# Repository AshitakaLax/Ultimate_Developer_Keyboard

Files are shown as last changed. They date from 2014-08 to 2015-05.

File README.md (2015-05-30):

Ultimate_Developer_Keyboard
===========================

Ultimate left single hand keyboard for Developing, Macros, and gaming. Code for MCU, Code for Windows service program, keyboard Hardware schematics, Keyboard Plastic templates.

### GOALS

While there are many great keyboards out there, I'm not aware of any that can support all of these.

1. Lower Cost (Many commercial keyboards have a low price)
2. Modularity (Nearly No keyboard is modular, but there are many nice features with modularity)
3. Open Source (Parallelized work is always faster, This is a hobby for me)
4. Flexible (If I want to have 64 keys I can, If I want 105 keys, I can, If I want 1000 keys I can), if I want it to be wireless, it can be,
5. Powerful (I don't want to be limited by the hardware as to what It can support).
6. Energy Flexible ( If I want to attach a fan, and LED lamp, I can. If I want to run off a Coin cell battery I can.)

I naturally can see the conflicting attributes in the list above. But with enough fore site, and structure, It should be possible.

### ROAD MAP

These are the core features with the new version of the keyboard.

1. Layout Modular components(Keys, brains, Communications)
2. Create the Bare bones keyboard(pretty much copy 64keys, and Ergodox, directly to a USB connection)
3. Support direct I/O connection from one board to the other(like 64 keys)
4. Have keyboard Right hand keyboard run off coin cell battery, and be wireless

This Project is broken down into 3 sections

1. Keyboard Software - this is the embedded code on a custom dev board(Atmel Sam4E), with hopes to move to a smaller chip to save cost.
2. Windows Software - this will be the smart portion of the system. It will determine the current IDE, and switch to it's custom keyboard layout.
3. Keyboard Hardware - This is all of the documentation for the hardware of this system, schematics, STL's, etc...

This system will be developed with Industrial quality tools, mainly because I like my time.

Keyboard Software Tools - Atmel Studio 6.2
Windows Software Tools - Visual Studio 2010 Ultimate
Keyboard Hardware Tools - (PCB)Altium Designer ,(Plastics) TBD

Scratch Notes

right side board structure.

SAM L21E(32 pin chip 25 IO) PL0
coin cell battery ~250mAh rechargeable
cpu pwr use 25 uA/Mhz (since speed isn't a factor) 1.2 mA when active
//since we can sleep, with a specific wakeup pin we can use
sleep/standby is 25uAmp.
NRF24L01+
tx is 7 mA
power down mode 4.2uA

standby sum of power
4.2uA
25uA

This right hand design is a asynchronous design to send keys as soon as they are pressed.
 and as soon as they aren't pressed

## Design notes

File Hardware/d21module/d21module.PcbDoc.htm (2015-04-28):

Reporting Options

# File in Previous Format

Date | : | 11/26/2014
Time | : | 1:07:59 PM
Filename | : | C:\Users\MIS\Desktop\workspace\Ultimate_Developer_Keyboard\Hardware\d21module\d21module.PcbDoc

Version | Warning
Release 12 | CAUTION - Air Gap Width previously controlled by Clearance rule is now controlled by Polygon Connect Style rule's newly introduced Air Gap Width (set to default value). Suggest reviewing each Polygon Connect Style rule's Air Gap Width attribute for correctness.
Release 13 | CAUTION - Silkscreen Over Component Pads Rules are converted to Silk To Solder Mask Clearance Rules. Suggest examining rule scopes for accuracy.

This file was generated by an earlier version of the software

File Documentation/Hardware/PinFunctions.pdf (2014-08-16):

P1

| | 3.3V | 1 | 2 | GND
MoistureSensor1 | I/O | PD0 | 3 | 4 | PB13 | I/O | MoistureSensor4
MoistureSensor2 | I/O | PB14 | 5 | 6 | PD1 | I/O | MoistureSensor5
MoistureSensor3 | I/O | PD2 | 7 | 8 | PA29 | I/O | MoistureSensor6

P2

3.3V PB1 | 1 | 2 | GND PB0
TXD0 | | 3 | 4 | RXD0
| A16 | PA20 | 5 | 6 | PA19 | A15
I/O | PA17 | 7 | 8 | PB2 | CTS0/AFE1_AD0 Voltage Sensor
CurrentSensor | AFE1_AD1 | PB3 | 9 | 10 | PA21 | RXD1
| I/O | PD30 | 11 | 12 | PA22 | TXD1
| MOSI | PA13 | 13 | 14 | PA16 | TIOB1 | Thruster
| SCK1/A19 | PA23 | 15 | 16 | PD27 | I/O
Thruster | TIOA1 | PA15 | 17 | 18 | PA14 | SPCK
| I/O | PD25 | 19 | 20 | PD26 | I/O
| I/O | PD24 | 21 | 22 | PA24 | RTS1/A20
Headlight | PWMH3 | PD23 | 23 | 24 | PA25 | CTS1/A23
Headlight | PWMH2 | PD22 | 25 | 26 | PA26 | TIOA2 | Thruster
Thruster | PWMH1 | PD21 | 27 | 28 | PA11 | I/O
Thruster | PWMH0 | PD20 | 29 | 30 | PA10 | UTXD0
| I/O | PD19 | 31 | 32 | PA12 | MISO

P3

| | 3.3V | 1 | 2 | GND
| I/O | PD3 | 3 | 4 | PD4 | I/O
| I/O | PD5 | 5 | 6 | PD6 | I/O
| I/O | PD7 | 7 | 8 | PA31 | I/O
| I/O | PA30 | 9 | 10 | PA6 | UTXD1
| I/O | PD8 | 11 | 12 | PA28 | I/O
| I/O | PD9 | 13 | 14 | PD29 | I/O
| I/O | PD15 | 15 | 16 | PA0 | TIOA0 | Thruster
| I/O | PD10 | 17 | 18 | PA1 | TIOB0 | Thruster
| I/O | PD11 | 19 | 20 | PA2 | I/O
| I/O | PD12 | 21 | 22 | PA3 | TWD0 | Accelerometer
| I/O | PD13 | 23 | 24 | PD14 | I/O
| I/O | PD16 | 25 | 26 | PA4 | TWCK0 | Accelerometer
Sonar1 | URXD0 | PA9 | 27 | 28 | PD17 | I/O
Sonar2 | URXD1 | PA5 | 29 | 30 | PD28 | I/O
Thruster | TIOB2 | PA27 | 31 | 32 | PD18 | I/O

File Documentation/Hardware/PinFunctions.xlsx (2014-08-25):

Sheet: roboSub
 |  |  | P1
 |  | 3.3V | 1 | 2 | GND
MoistureSensor1 | I/O | PD0 | 3 | 4 | PB13 | I/O | MoistureSensor4
MoistureSensor2 | I/O | PB14 | 5 | 6 | PD1 | I/O | MoistureSensor5
MoistureSensor3 | I/O | PD2 | 7 | 8 | PA29 | I/O | MoistureSensor6
 |  |  | P2
 |  | 3.3V | 1 | 2 | GND
 | TXD0 | PB1 | 3 | 4 | PB0 | RXD0
 | A16 | PA20 | 5 | 6 | PA19 | A15
 | I/O | PA17 | 7 | 8 | PB2 | CTS0/AFE1_AD0 | Voltage Sensor
CurrentSensor | AFE1_AD1 | PB3 | 9 | 10 | PA21 | RXD1
 | I/O | PD30 | 11 | 12 | PA22 | TXD1
 | MOSI | PA13 | 13 | 14 | PA16 | TIOB1 | Thruster
 | SCK1/A19 | PA23 | 15 | 16 | PD27 | I/O
Thruster | TIOA1 | PA15 | 17 | 18 | PA14 | SPCK
 | I/O | PD25 | 19 | 20 | PD26 | I/O
 | I/O | PD24 | 21 | 22 | PA24 | RTS1/A20
Headlight | PWMH3 | PD23 | 23 | 24 | PA25 | CTS1/A23
Headlight | PWMH2 | PD22 | 25 | 26 | PA26 | TIOA2 | Thruster
Thruster | PWMH1 | PD21 | 27 | 28 | PA11 | I/O
Thruster | PWMH0 | PD20 | 29 | 30 | PA10 | UTXD0
 | I/O | PD19 | 31 | 32 | PA12 | MISO
 |  |  | P3
 |  | 3.3V | 1 | 2 | GND
 | I/O | PD3 | 3 | 4 | PD4 | I/O
 | I/O | PD5 | 5 | 6 | PD6 | I/O
 | I/O | PD7 | 7 | 8 | PA31 | I/O
 | I/O | PA30 | 9 | 10 | PA6 | UTXD1
 | I/O | PD8 | 11 | 12 | PA28 | I/O
 | I/O | PD9 | 13 | 14 | PD29 | I/O
 | I/O | PD15 | 15 | 16 | PA0 | TIOA0 | Thruster
 | I/O | PD10 | 17 | 18 | PA1 | TIOB0 | Thruster
 | I/O | PD11 | 19 | 20 | PA2 | I/O
 | I/O | PD12 | 21 | 22 | PA3 | TWD0 | Accelerometer
 | I/O | PD13 | 23 | 24 | PD14 | I/O
 | I/O | PD16 | 25 | 26 | PA4 | TWCK0 | Accelerometer
Sonar1 | URXD0 | PA9 | 27 | 28 | PD17 | I/O
Sonar2 | URXD1 | PA5 | 29 | 30 | PD28 | I/O
Thruster | TIOB2 | PA27 | 31 | 32 | PD18 | I/O

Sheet: UltimateKeyboard
This is the pinout for the Ultimate Keyboard
 |  |  |  | P1
 |  | 3.3V |  | 1 | 2 | GND
 | I/O | PD0 |  | 3 | 4 | PB13 | B | I/O
 | I/O | PB14 |  | 5 | 6 | PD1 | D | I/O
 | I/O | PD2 |  | 7 | 8 | PA29 | A | I/O
 |  |  |  | P2
 |  | 3.3V |  | 1 | 2 | GND
 | TXD0 | PB1 |  | 3 | 4 | PB0 | B | RXD0
 | A16 | PA20 |  | 5 | 6 | PA19 | A | A15
 | I/O | PA17 |  | 7 | 8 | PB2 | B | CTS0/AFE1_AD0
 | AFE1_AD1 | PB3 |  | 9 | 10 | PA21 | A | RXD1
 | I/O | PD30 |  | 11 | 12 | PA22 | A | TXD1
 | MOSI | PA13 |  | 13 | 14 | PA16 | A | TIOB1
 | SCK1/A19 | PA23 |  | 15 | 16 | PD27 | D | I/O
 | TIOA1 | PA15 |  | 17 | 18 | PA14 | A | SPCK
 | I/O | PD25 |  | 19 | 20 | PD26 | D | I/O
 | I/O | PD24 |  | 21 | 22 | PA24 | A | RTS1/A20
 | PWMH3 | PD23 |  | 23 | 24 | PA25 | A | CTS1/A23
 | PWMH2 | PD22 |  | 25 | 26 | PA26 | A | TIOA2
 | PWMH1 | PD21 |  | 27 | 28 | PA11 | A | I/O
 | PWMH0 | PD20 |  | 29 | 30 | PA10 | A | UTXD0
 | I/O | PD19 |  | 31 | 32 | PA12 | A | MISO
 |  |  |  | P3
 |  | 3.3V |  | 1 | 2 | GND
kMatrix Out 0 | I/O | PD3 | D | 3 | 4 | PD4 | D | I/O
kMatrix Out 1 | I/O | PD5 | D | 5 | 6 | PD6 | D | I/O
kMatrix Out 2 | I/O | PD7 | D | 7 | 8 | PA31 | A | I/O
kMatrix Out 3 | I/O | PA30 | A | 9 | 10 | PA6 | A | UTXD1
kMatrix Out 4 | I/O | PD8 | D | 11 | 12 | PA28 | A | I/O
kMatrix Out 5 | I/O | PD9 | D | 13 | 14 | PD29 | D | I/O
kMatrix Out 6 | I/O | PD15 | D | 15 | 16 | PA0 | A | TIOA0
kMatrix Out 7 | I/O | PD10 | D | 17 | 18 | PA1 | A | TIOB0
kMatrix In 0 | I/O | PD11 | D | 19 | 20 | PA2 | A | I/O
kMatrix In 1 | I/O | PD12 | D | 21 | 22 | PA3 | A | TWD0
kMatrix In 2 | I/O | PD13 | D | 23 | 24 | PD14 | D | I/O
kMatrix In 3 | I/O | PD16 | D | 25 | 26 | PA4 | A | TWCK0
kMatrix In 4 | URXD0 | PA9 | A | 27 | 28 | PD17 | D | I/O
kMatrix In 5 | URXD1 | PA5 | A | 29 | 30 | PD28 | D | I/O
kMatrix In 6 | TIOB2 | PA27 | A | 31 | 32 | PD18 | D | I/O | kMatrix In 7

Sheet: NRF24L01+
 |  |  | P1
 |  | 3.3V | 1 | 2 | GND
MoistureSensor1 | I/O | PD0 | 3 | 4 | PB13 | I/O | MoistureSensor4
MoistureSensor2 | I/O | PB14 | 5 | 6 | PD1 | I/O | MoistureSensor5
MoistureSensor3 | I/O | PD2 | 7 | 8 | PA29 | I/O | MoistureSensor6
 |  |  | P2 |  |  |  |  |  |  | NRF24L01+
 |  | 3.3V | 1 | 2 | GND |  |  |  | P2-2 | GND | 1 | 2 | 3.3V | P2-1
 | TXD0 | PB1 | 3 | 4 | PB0 | RXD0 |  | PD27 | P2-16 | CE | 3 | 4 | CSN | P2-11 | PD30
 | A16 | PA20 | 5 | 6 | PA19 | A15 |  | PA14 | P2-18 | SCK | 5 | 6 | MOSI | P2-13 | PA13
 | I/O | PA17 | 7 | 8 | PB2 | CTS0/AFE1_AD0 | Voltage Sensor | PA12 | P2-32 | MISO | 7 | 8 | IRQ
CurrentSensor | AFE1_AD1 | PB3 | 9 | 10 | PA21 | RXD1
 | I/O | PD30 | 11 | 12 | PA22 | TXD1
 | MOSI | PA13 | 13 | 14 | PA16 | TIOB1 | Thruster
 | SCK1/A19 | PA23 | 15 | 16 | PD27 | I/O
Thruster | TIOA1 | PA15 | 17 | 18 | PA14 | SPCK
 | I/O | PD25 | 19 | 20 | PD26 | I/O
 | I/O | PD24 | 21 | 22 | PA24 | RTS1/A20
Headlight | PWMH3 | PD23 | 23 | 24 | PA25 | CTS1/A23
Headlight | PWMH2 | PD22 | 25 | 26 | PA26 | TIOA2 | Thruster
Thruster | PWMH1 | PD21 | 27 | 28 | PA11 | I/O
Thruster | PWMH0 | PD20 | 29 | 30 | PA10 | UTXD0
 | I/O | PD19 | 31 | 32 | PA12 | MISO
 |  |  | P3
 |  | 3.3V | 1 | 2 | GND
 | I/O | PD3 | 3 | 4 | PD4 | I/O
 | I/O | PD5 | 5 | 6 | PD6 | I/O
 | I/O | PD7 | 7 | 8 | PA31 | I/O
 | I/O | PA30 | 9 | 10 | PA6 | UTXD1
 | I/O | PD8 | 11 | 12 | PA28 | I/O
 | I/O | PD9 | 13 | 14 | PD29 | I/O
 | I/O | PD15 | 15 | 16 | PA0 | TIOA0 | Thruster
 | I/O | PD10 | 17 | 18 | PA1 | TIOB0 | Thruster
 | I/O | PD11 | 19 | 20 | PA2 | I/O
 | I/O | PD12 | 21 | 22 | PA3 | TWD0 | Accelerometer
 | I/O | PD13 | 23 | 24 | PD14 | I/O
 | I/O | PD16 | 25 | 26 | PA4 | TWCK0 | Accelerometer
Sonar1 | URXD0 | PA9 | 27 | 28 | PD17 | I/O
Sonar2 | URXD1 | PA5 | 29 | 30 | PD28 | I/O
Thruster | TIOB2 | PA27 | 31 | 32 | PD18 | I/O

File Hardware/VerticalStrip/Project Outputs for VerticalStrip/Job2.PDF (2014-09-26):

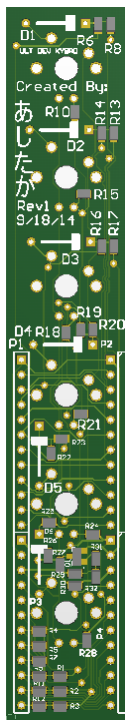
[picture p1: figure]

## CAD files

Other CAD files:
Documentation/Hardware/parts/keyboardTemplate/plate template.dwg

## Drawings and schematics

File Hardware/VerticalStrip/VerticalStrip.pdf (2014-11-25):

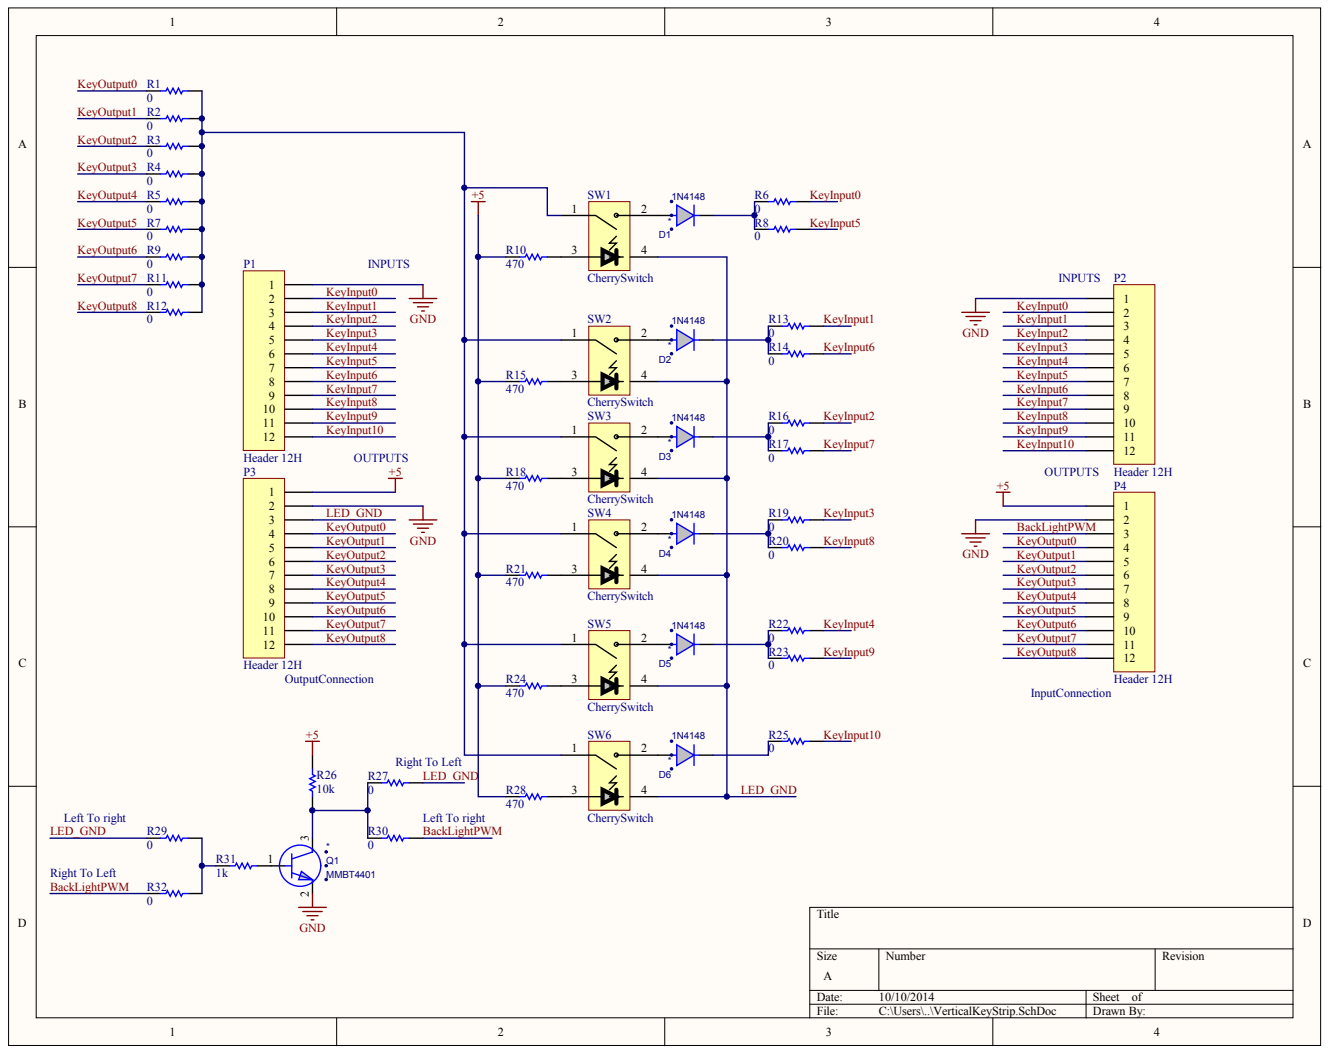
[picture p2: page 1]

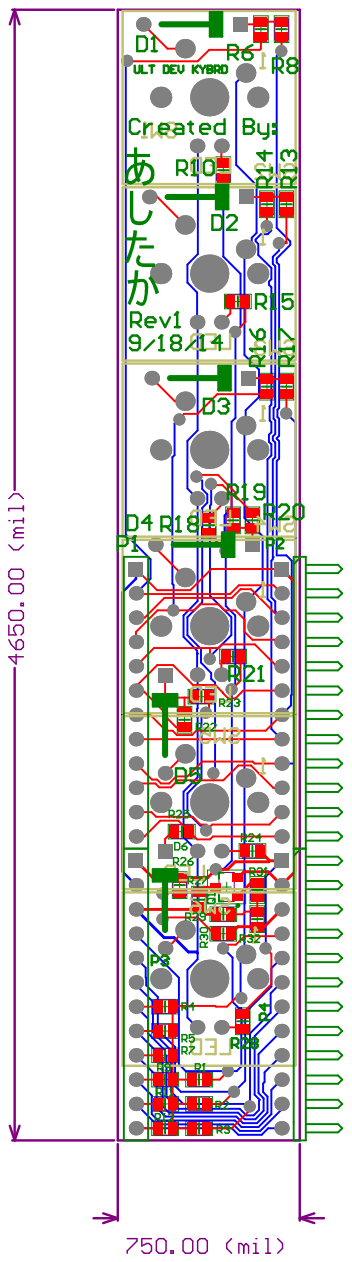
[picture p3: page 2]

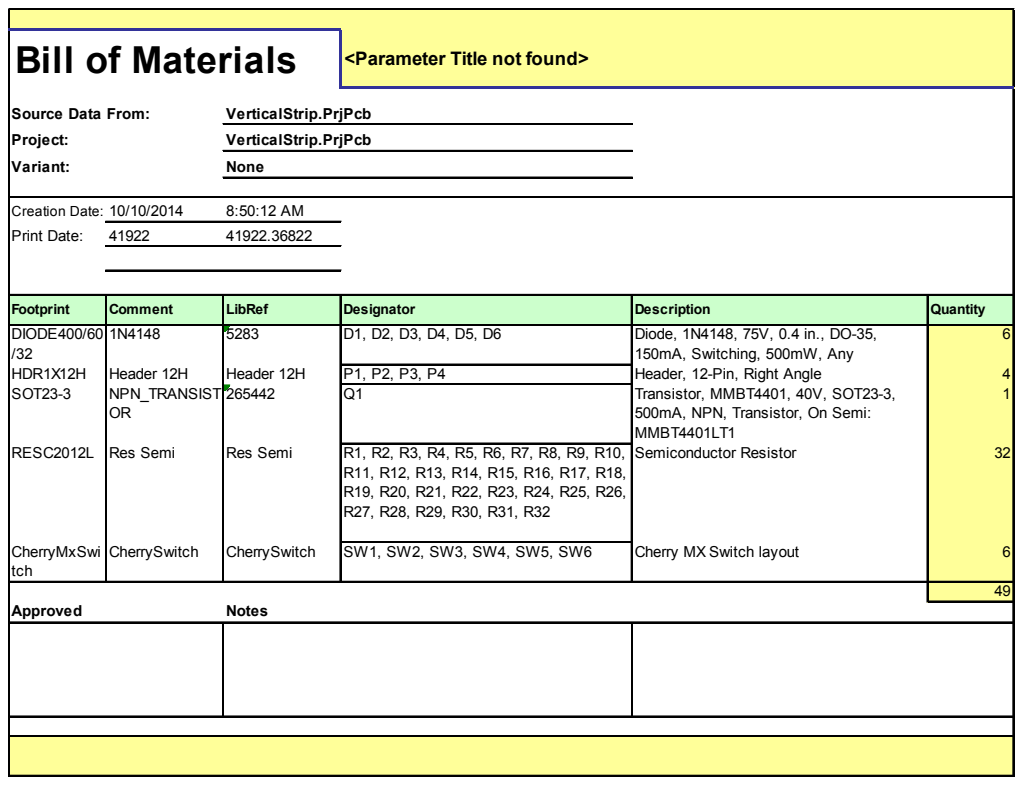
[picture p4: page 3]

Footprint | Comment | LibRef | Designator | Description | Quantity

500mA, NPN, Transistor, On Semi:
MMBT4401LT1

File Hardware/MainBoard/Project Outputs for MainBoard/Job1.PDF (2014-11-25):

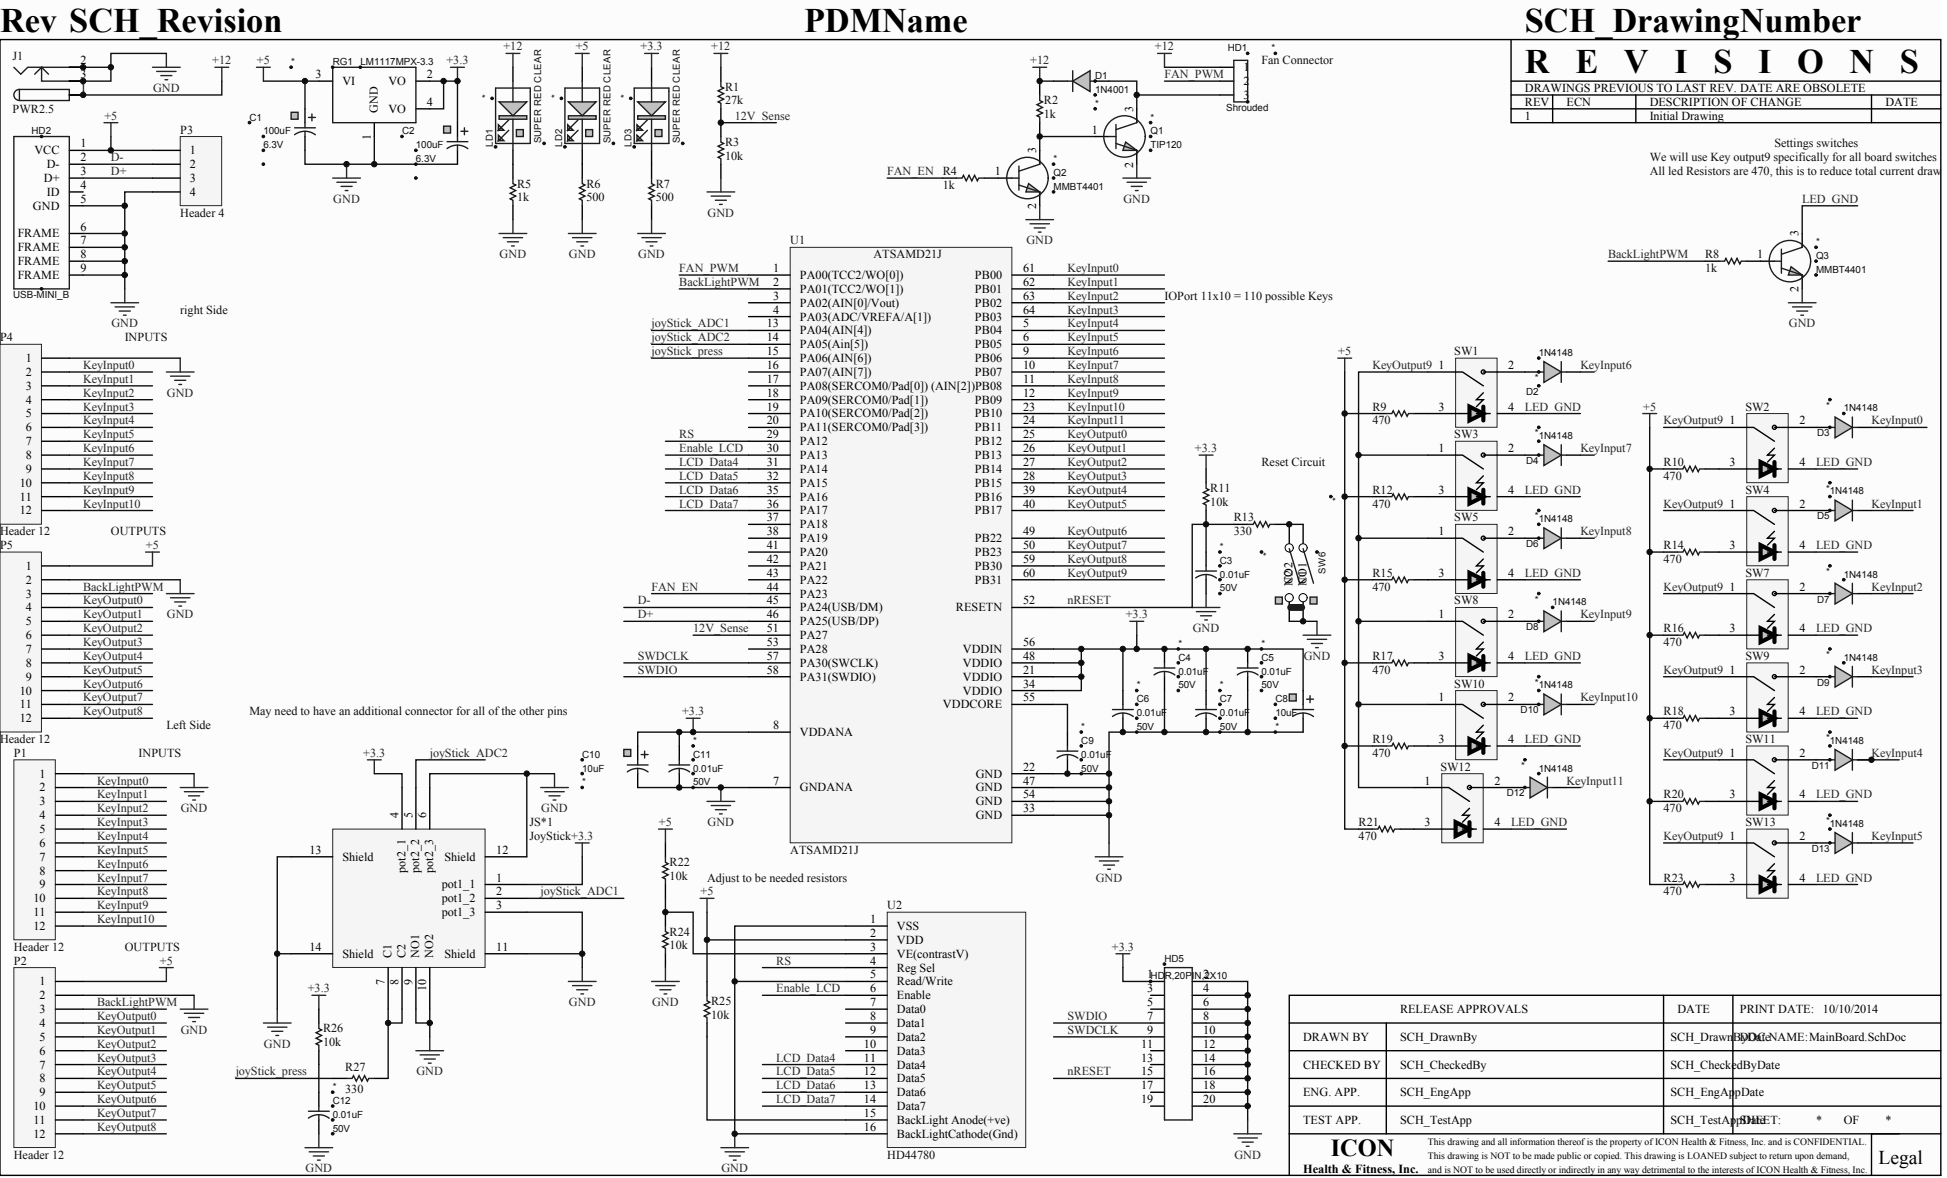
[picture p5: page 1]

DRAWINGS PREVIOUS TO LAST REV. DATE ARE OBSOLETE

REV | ECN | DESCRIPTION OF CHANGE | DATE
1 | | Initial Drawing

We will use Key output9 specifically for all board switches
All led Resistors are 470, this is to reduce total current draw

May need to have an additional connector for all of the other pins

Adjust to be needed resistors

VDD 2
VE(contrastV) 3

RS | Reg Sel 4 Read/Write 5

This drawing and all information thereof is the property of ICON Health & Fitness, Inc. and is CONFIDENTIAL.
This drawing is NOT to be made public or copied. This drawing is LOANED subject to return upon demand,

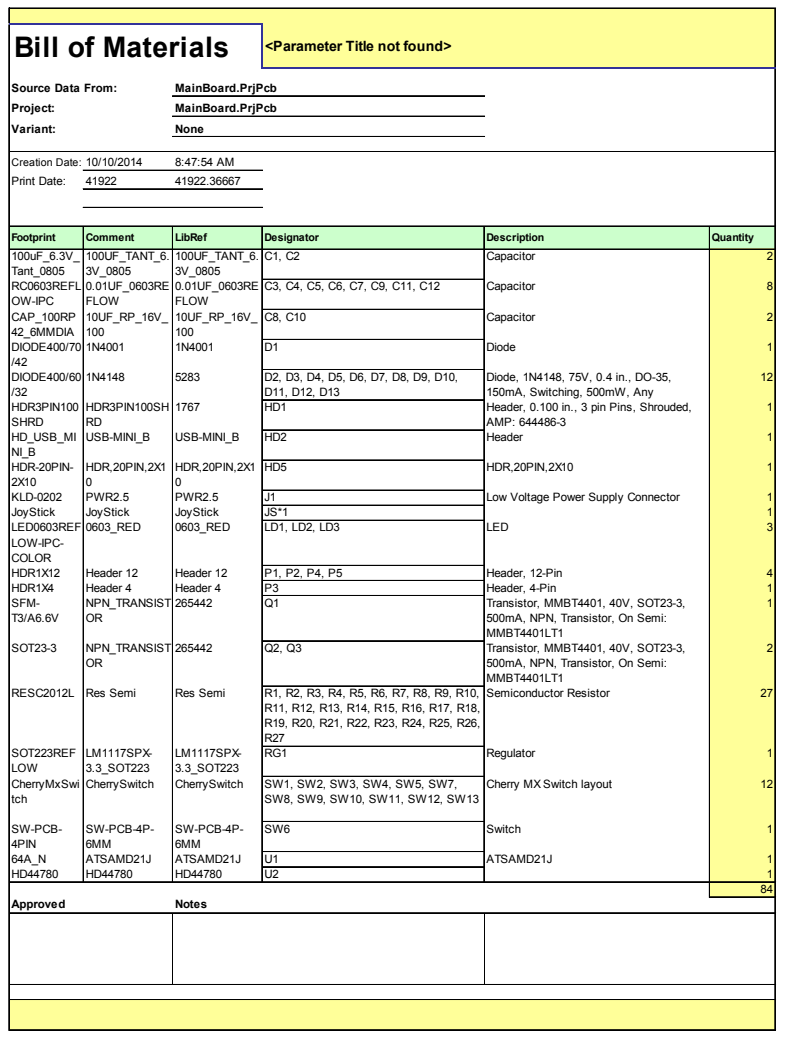
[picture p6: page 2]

500mA, NPN, Transistor, On Semi:
MMBT4401LT1

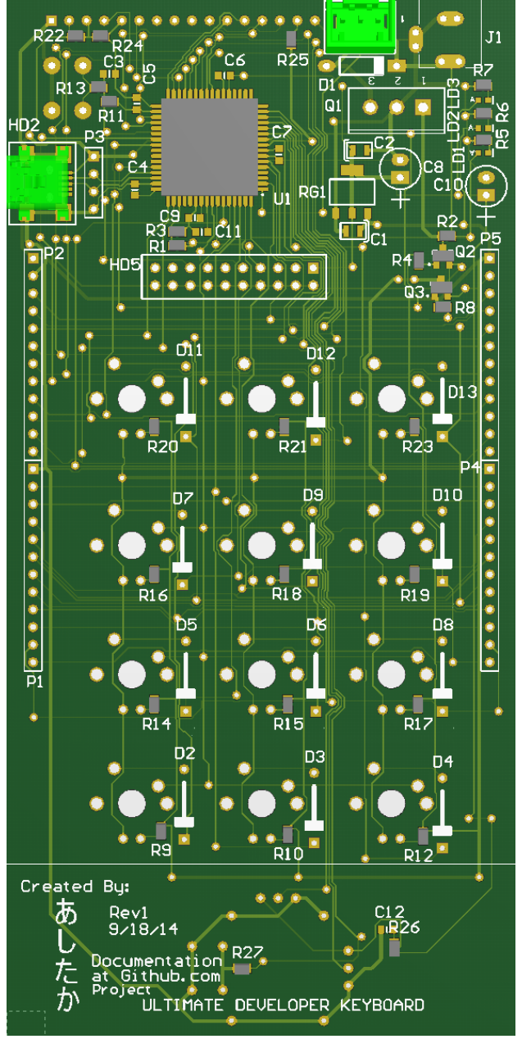
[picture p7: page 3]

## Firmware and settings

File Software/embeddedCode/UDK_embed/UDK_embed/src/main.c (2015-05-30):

/**
 * \file
 *
 * \brief Main functions for Keyboard example
 *
 * Copyright (c) 2009-2014 Atmel Corporation. All rights reserved.
 *
 * \asf_license_start
 *
 * \page License
 *
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
 * 3. The name of Atmel may not be used to endorse or promote products derived
 *    from this software without specific prior written permission.
 *
 * 4. This software may only be redistributed and used in connection with an
 *    Atmel microcontroller product.
 *
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
 * \asf_license_stop
 *
 */

#include <asf.h>
#include "conf_usb.h"
#include "ui.h"
#include "udk/keyboard.h"

static volatile bool main_b_kbd_enable = false;


/*! \brief Main function. Execution starts here.
 */
int main(void)
{
	irq_initialize_vectors();
	cpu_irq_enable();

	// Initialize the sleep manager
	sleepmgr_init();

#if !SAMD21 && !SAMR21 && !SAMD11
	sysclk_init();
	board_init();

#else
	system_init();
#endif
	//initialize the keyboard
	initKeyboard();//initialize the keyboard
	ui_init();
	ui_powerdown();

	// Start USB stack to authorize VBus monitoring
	udc_start();

	// The main loop manages only the power mode
	// because the USB management is done by interrupt
	while (true) {
#ifdef   USB_DEVICE_LOW_SPEED
		// No USB "Keep a live" interrupt available in low speed
		// to scan keyboard interface then use main loop
		if (main_b_kbd_enable) {
			static volatile uint16_t virtual_sof_sub = 0;
			if (sysclk_get_cpu_hz()/50000 ==
				virtual_sof_sub++) {
				virtual_sof_sub = 0;
				static uint16_t virtual_sof = 0;
				ui_process(virtual_sof++);
			}
		}
#else
		// to scan keyboard interface then use main loop
		if (main_b_kbd_enable) {
			static volatile uint16_t virtual_sof_sub = 0;
			uint32_t cpuSpeed =sysclk_get_cpu_hz();
			if (cpuSpeed/500000 ==
				virtual_sof_sub++) {
				virtual_sof_sub = 0;
				static uint16_t virtual_sof = 0;
				ui_process(virtual_sof++);
			}
		}
		
		//todo improve this by adding a interrupt to the system
		//sleepmgr_enter_sleep();
#endif
	}
}

void main_suspend_action(void)
{
	ui_powerdown();
}

void main_resume_action(void)
{
	ui_wakeup();
}

void main_sof_action(void)
{
	if (!main_b_kbd_enable)
		return;

	if(udd_get_frame_number() % 10 == 0)
	{//every 10 ms
		ui_process(udd_get_frame_number());
	}
}

void main_remotewakeup_enable(void)
{
	ui_wakeup_enable();
}

void main_remotewakeup_disable(void)
{
	ui_wakeup_disable();
}

bool main_kbd_enable(void)
{
	main_b_kbd_enable = true;
	return true;
}

void main_kbd_disable(void)
{
	main_b_kbd_enable = false;
}


/**
 * \mainpage ASF USB Device HID Keyboard
 *
 * \section intro Introduction
 * This example shows how to implement a USB Device HID Keyboard
 * on Atmel MCU with USB module.
 * The application note AVR4903 provides information about this implementation.
 *
 * \section startup Startup
 * The example uses the buttons or sensors available on the board
 * to simulate a standard keyboard.
 * After loading firmware, connect the board (EVKxx,Xplain,...) to the USB Host.
 * When connected to a USB host system this application provides a keyboard application
 * in the Unix/Mac/Windows operating systems.
 * This example uses the native HID driver for these operating systems.
 *
 * \copydoc UI
 *
 * \section example About example
 *
 * The example uses the following module groups:
 * - Basic modules:
 *   Startup, board, clock, interrupt, power management
 * - USB Device stack and HID modules:
 *   <br>services/usb/
 *   <br>services/usb/udc/
 *   <br>services/usb/class/hid/
 *   <br>services/usb/class/hid/keyboard/
 * - Specific implementation:
 *    - main.c,
 *      <br>initializes clock
 *      <br>initializes interrupt
 *      <br>manages UI
 *    - specific implementation for each target "./examples/product_board/":
 *       - conf_foo.h   configuration of each module
 *       - ui.c        implement of user's interface (buttons, leds)
 */

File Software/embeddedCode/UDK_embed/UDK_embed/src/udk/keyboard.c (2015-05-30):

/*
 * keyboard.c
 *
 * Created: 12/12/2014 8:49:02 AM
 *  Author: Levi.Balling
 */ 

#include <asf.h>
#include "keyboard.h"
#include "ioport.h"
#include <delay.h>


static KEY_BOARD_OBJ keyBoard;
//add each the number of keys per row
static uint8_t row0Keys = 3;//we currently have Rows 3,4,5
static uint8_t rowOffset = 3;//row offset
static uint8_t columns = 6;

#define NUMBER_OF_KEY_DATA  10
#define VALID_KEY_COUNT  10 // there has to be 5 checks on the pin in order for it to be valid

typedef struct key_data_buffer
{
	HID_KEY_DATA downKey[NUMBER_OF_KEY_DATA];
	HID_KEY_DATA releasedKey[NUMBER_OF_KEY_DATA];
	uint8_t downKeyCounter;//keep track of the number down keys in the buffer
	uint8_t releaseKeyCounter;//keep track of the number of keys released
}KEY_DATA_BUFFER;

static KEY_DATA_BUFFER keyBuffer;
static HID_KEY_DATA downKeys[NUMBER_OF_KEY_DATA];//this is all of the keys that are currently being pressed
static HID_KEY_DATA releasedKeys[NUMBER_OF_KEY_DATA];//this is all of the keys that are currently being pressed

static HID_KEY_DATA hidMapping[18];
static bool backLight;

static void clearDownKeys(void);
static void clearReleasedKeys(void);
static void addDownKeyToBuffer(HID_KEY_DATA data);
static void addReleaseKeyToBuffer(HID_KEY_DATA data);

/**
 * Adds a key to the downKey buffer to send the keys out
 */

static void setupMapping(void)
{
	uint8_t index = 0;
	//setup the 18 keys
	//key 0
	hidMapping[index].modifiers = 0;
	hidMapping[index++].value = UDK_HID_A;

	//key 1
	hidMapping[index].modifiers = 0;
	hidMapping[index++].value = UDK_HID_S;

	//key 2
	hidMapping[index].modifiers = 0;
	hidMapping[index++].value = UDK_HID_D;

	//key 3
	hidMapping[index].modifiers = 0;
	hidMapping[index++].value = UDK_HID_F;

	//key 4
	hidMapping[index].modifiers = 0;
	hidMapping[index++].value = UDK_HID_G;

	//key 5
	hidMapping[index].modifiers = 0;
	hidMapping[index++].value = UDK_HID_H;

	//key 6
	hidMapping[index].modifiers = 0;
	hidMapping[index++].value = UDK_HID_Q;

	//key 7
	hidMapping[index].modifiers = 0;
	hidMapping[index++].value = UDK_HID_W;

	//key 8
	hidMapping[index].modifiers = 0;
	hidMapping[index++].value = UDK_HID_E;

	//key 9
	hidMapping[index].modifiers = 0;
	hidMapping[index++].value = UDK_HID_R;

	//key 10
	hidMapping[index].modifiers = 0;
	hidMapping[index++].value = UDK_HID_T;

	//key 11
	hidMapping[index].modifiers = 0;
	hidMapping[index++].value = UDK_HID_Y;

	//key 12
	hidMapping[index].modifiers = 0;
	hidMapping[index++].value = UDK_HID_Z;

	//key 13
	hidMapping[index].modifiers = 0;
	hidMapping[index++].value = UDK_HID_X;

	//key 14
	hidMapping[index].modifiers = 0;
	hidMapping[index++].value = UDK_HID_C;

	//key 15
	hidMapping[index].modifiers = 0;
	hidMapping[index++].value = UDK_HID_V;

	//key 16
	hidMapping[index].modifiers = 0;
	hidMapping[index++].value = UDK_HID_B;

	//key 17
	hidMapping[index].modifiers = 0;
	hidMapping[index++].value = UDK_HID_N;
}


/**
 * Initializes all of the keyboard keys
 */
void initKeyboard(void)
{
	uint8_t i = 0;
	uint8_t j = 0;
	uint8_t index = 0;
	setupMapping();
	keyBoard.keyIsDown = false;
	keyBoard.keysPressed = 0;
	clearReleasedKeys();
	clearDownKeys();

	//setup the backlight 
	ioport_set_pin_dir(GPIO_BACKLIGHT_OUT, IOPORT_DIR_OUTPUT);
	ioport_set_pin_level(GPIO_BACKLIGHT_OUT, IOPORT_PIN_LEVEL_LOW);//all low except for the active row
	backLight = true;

	for(i = 0; i < row0Keys; i++)
	{

		keyBoard.rows[i].row = (KEY_OUTPUT)(KEY_OUT_0 + i+ rowOffset);
		keyBoard.rows[i].rowKeyCount = 0;
		//outputs
		ioport_set_pin_dir(keyBoard.rows[i].row, IOPORT_DIR_OUTPUT);
		ioport_set_pin_level(keyBoard.rows[i].row, IOPORT_PIN_LEVEL_LOW);//all low except for the active row

		for(j = 0; j < columns; j++)
		{
			KEY_OBJ * currentKey = &keyBoard.rows[i].rowOfKeys[j];

			if(columns == 5)
			{
				currentKey->column = ((KEY_INPUT)KEY_IN_10);

			}
			else
			{
				currentKey->column = ((KEY_INPUT)KEY_IN_0 + j);
			}
			currentKey->keyIsDown = false;
			currentKey->justPressed = false;
			currentKey->keyReleased = false;
			currentKey->validCount = 0;
			currentKey->releaseCount = 0;



			currentKey->data.modifiers = hidMapping[index].modifiers;
			currentKey->data.value = hidMapping[index++].value;

			//inputs
			//set the direction
			//set the
			ioport_set_pin_dir(currentKey->column, IOPORT_DIR_INPUT);//set direction to input
			ioport_set_pin_mode(currentKey->column, (IOPORT_MODE_PULLDOWN));
		}

	}
}
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

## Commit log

2014-08-16 Added some more documents about the specific board that I'm developing with. I'v also made some pin functions. I'm just working on implementing the keys.
    [PinFunctions.xlsx]
2014-08-25 added support for reading the pins in and setting the matrix out also.
    [PinFunctions.xlsx]
2014-08-29 compiles with the current code to fetch the keys from the board. and return an array of all the recently changed keys. This includes held, pressed, and released.
2014-09-01 Add more documentation, still have more work todo with the board layout. It is the next step.
    [plate template.dwg]
2014-09-01 added the main schematic and the library to support it. This library requires connection to existing libraries.
    [MainBoard.PrjPcb, MainBoard.SchDoc, mainBoardLib.SchLib]
2014-09-02 added the dc input to the schematic.
    [MainBoard.SchDoc]
2014-09-03 added more to the schematic, and the relay i'm using for the fan.
    [MainBoard.SchDoc, mainBoardLib.SchLib]
2014-09-06 Added the pcb to the hardware file. I haven't finished the pcb. still need to do a lot on it.
    [MainBoard.PcbDoc, MainBoard.PrjPcb, MainBoard.SchDoc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]
2014-09-08 didn't add the pcb libraries to the repo due to propreitary reasons. Saved the pcb for the current state.
    [MainBoard.PcbDoc, MainBoard.SchDoc]
2014-09-14 added a library to the repo, and the vertical key strip.
    [MainBoard.PcbDoc, MainBoard.PrjPcb, MainBoard.SchDoc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]
2014-09-26 added a lot of major pcb files for the board. I have submitted them to IMALL for fabrication.
    [MainBoard.PcbDoc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]
2014-11-25 added all of the other items
    [DevModule.SchDoc, MainBoard.SchDoc, d21Module.PrjPCB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]
2015-01-18 added the initializing of the pins for the keyboard.
    [d21Module.PrjPCB, d21module.PcbDoc]
2015-02-11 updated the keylogic to have some keys to see how it maps to the board.
2015-02-21 updated the code for the keyboard, and the logic. it now pulls each key once every 1 millisecond. and the debounce requires 5 valid key presses in a row, allowing for a response time of 5 ms for a ke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
2015-02-21 updated the keyboard to handle debouncing better.
    keys work well, there may be a few glitches, but it is getting there. still need to add the pwm, to the keys.
    [keyboard.c]
2015-04-28 added several project files.
    [64XkeySchem.SchDoc, 64XkeysPcb.PcbDoc, 64XkeysProj.PrjPcb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]
2015-05-30 added the simple keyboard to figure out how it works.
    [Mickeyboard2.PcbDoc, keyboard.SchDoc]
2015-06-03 added ascii are version of the board.
